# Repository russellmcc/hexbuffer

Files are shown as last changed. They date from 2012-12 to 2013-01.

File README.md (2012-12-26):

This is a simple buffered multiple for eurorack modular synth systems.  Three buffered copies of each input are provided, and the second input is normalled to the first to provide six copies when there is only one input.

This work is licensed under a [Creative Commons Attribution-ShareAlike 3.0 Unported License.](http://creativecommons.org/licenses/by-sa/3.0/deed.en_US)

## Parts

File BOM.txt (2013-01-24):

Connectors:
1x MO8x2     Eurorack power connector
8x erthenvar jack

Semiconductors
3x DIP-8     LF353 op amp

Capacitor
3x 2.5mm .1uF ceramic capacitor

Cost:
Components : 6
PCB        : 6
Panel      : 6
Total      : 18

Mouser link to project:
http://www.mouser.com/ProjectManager/ProjectDetail.aspx?AccessID=8b942c2668

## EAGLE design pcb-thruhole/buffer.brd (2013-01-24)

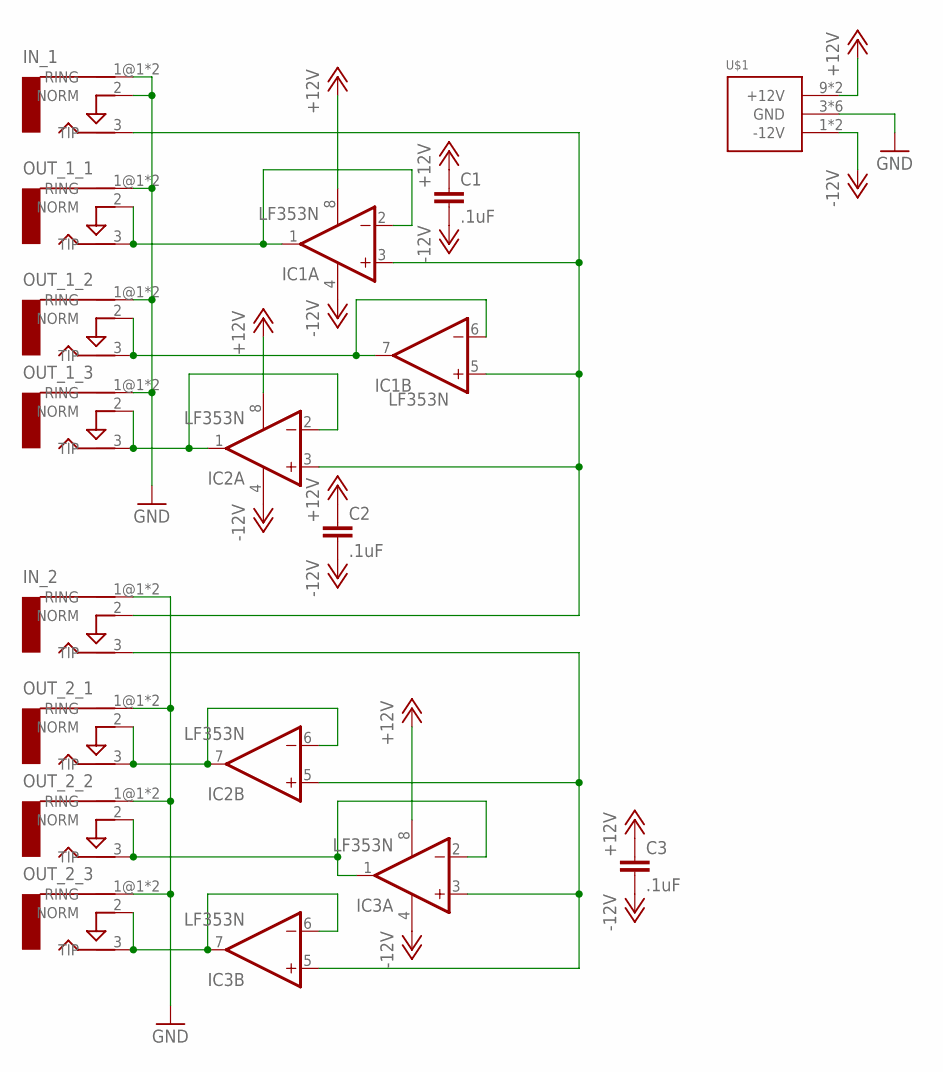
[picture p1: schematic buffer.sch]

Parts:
C1, C2, C3: .1uF; CAP-PTH-SMALL
IC1, IC2, IC3: LF353N; DIL08
IN_1, IN_2: AUDIO-JACKERTHENVAR; ERTHENVAR-JACK
OUT_1_1, OUT_1_2, OUT_1_3, OUT_2_1, OUT_2_2, OUT_2_3: AUDIO-JACKERTHENVAR; ERTHENVAR-JACK
U$1: POWER_SIMPLE16; POWER_16

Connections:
+12V: C1.1, C2.1, C3.1, IC1.8 (V+), IC2.8 (V+), IC3.8 (V+), U$1.9 (+12V), U$1.10 (+12V)
-12V: C1.2, C2.2, C3.2, IC1.4 (V-), IC2.4 (V-), IC3.4 (V-), U$1.1 (-12V), U$1.2 (-12V)
GND: IN_1.1@1 (RING), IN_1.1@2 (RING), IN_1.2 (NORM), IN_2.1@1 (RING), IN_2.1@2 (RING), OUT_1_1.1@1 (RING), OUT_1_1.1@2 (RING), OUT_1_2.1@1 (RING), OUT_1_2.1@2 (RING), OUT_1_3.1@1 (RING), OUT_1_3.1@2 (RING), OUT_2_1.1@1 (RING), OUT_2_1.1@2 (RING), OUT_2_2.1@1 (RING), OUT_2_2.1@2 (RING), OUT_2_3.1@1 (RING), OUT_2_3.1@2 (RING), U$1.3 (GND), U$1.4 (GND), U$1.5 (GND), U$1.6 (GND), U$1.7 (GND), U$1.8 (GND)
unnamed: IC1.1 (OUT), IC1.2 (-IN), OUT_1_1.2 (NORM), OUT_1_1.3 (TIP)
unnamed: IC2.1 (OUT), IC2.2 (-IN), OUT_1_3.2 (NORM), OUT_1_3.3 (TIP)
unnamed: IC1.6 (-IN), IC1.7 (OUT), OUT_1_2.2 (NORM), OUT_1_2.3 (TIP)
unnamed: IC1.3 (+IN), IC1.5 (+IN), IC2.3 (+IN), IN_1.3 (TIP), IN_2.2 (NORM)
unnamed: IC2.6 (-IN), IC2.7 (OUT), OUT_2_1.2 (NORM), OUT_2_1.3 (TIP)
unnamed: IC3.6 (-IN), IC3.7 (OUT), OUT_2_3.2 (NORM), OUT_2_3.3 (TIP)
unnamed: IC2.5 (+IN), IC3.3 (+IN), IC3.5 (+IN), IN_2.3 (TIP)
unnamed: IC3.1 (OUT), IC3.2 (-IN), OUT_2_2.2 (NORM), OUT_2_2.3 (TIP)

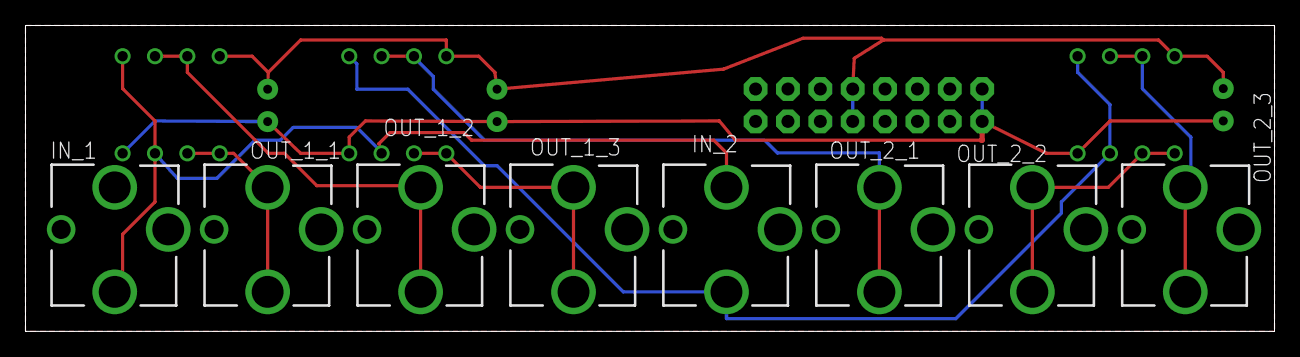
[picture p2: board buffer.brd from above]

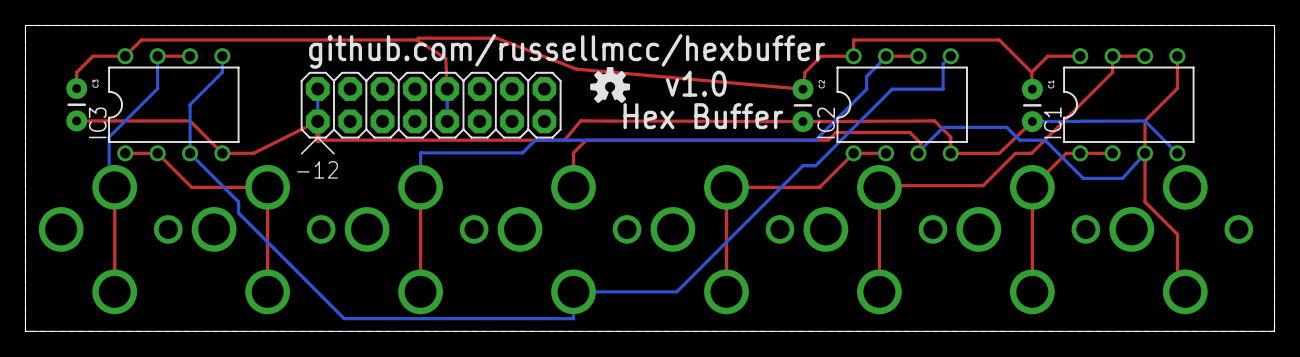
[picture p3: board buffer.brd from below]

Board: 2 copper layers, 98.0 x 24.0 mm, 16 parts (8 on the bottom side), 11 nets.

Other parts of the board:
U$6: OSHW-LOGO-S

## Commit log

2012-12-24 removed two airwires I accidentally left in.
    [buffer.brd]
2012-12-24 fix for bad routing
    [buffer.brd]
2012-12-24 made the ground plane the same side as the board and used the DRC to find the correct size
    [buffer.brd]
2012-12-24 switched to 10mil isolation on ground planes
    [buffer.brd]
2012-12-24 added thru hole version
    [buffer.brd, buffer.sch]
2012-12-24 fix for oopsy
    [buffer.brd]
2012-12-24 moved ICs to the back so they don't hit the jacks.
    [buffer.brd]
2012-12-26 moved the name to the place layer so it'll show up
    [buffer.brd]
2012-12-26 straightened som traces.
    [buffer.brd]
2012-12-26 switched panel to 5hp because the board has to be bigger
    [buffer.brd]
2012-12-27 added BOM
2013-01-24 moved some text off of holes, added url, made version 1.0
    [buffer.brd]
2013-01-27 better hole placement

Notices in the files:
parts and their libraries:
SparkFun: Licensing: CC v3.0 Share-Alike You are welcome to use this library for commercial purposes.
